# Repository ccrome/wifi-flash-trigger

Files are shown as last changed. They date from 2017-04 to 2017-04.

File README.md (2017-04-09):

# wifi-flash-trigger
ESP8266 + Arduino Wifi Flash trigger for high speed photography.  Uses esp-link as the wifi link to arduino

## Download esp-link
It’s here: https://github.com/jeelabs/esp-link/releases.

## Firmware versions:
esp-link: This seems to only work with esp-link v3.0.alpha0 - 2016-10-23, d0377bd.  https://github.com/jeelabs/esp-link
el-client: https://github.com/jeelabs/el-client (d559214ada405739fa235b13c7e2b42175ddbe95 tested)

## Flash the ESP8266
Flash to the esp8266: as per these instructions: https://github.com/jeelabs/esp-link/blob/master/FLASHING.md

esptool.py --port /dev/ttyUSB0 --baud 230400 write_flash -fs 32m -ff 80m 0x00000 boot_v1.6.bin 0x1000 user1.bin 0x3FC000 esp_init_data_default.bin 0x3FE000 blank.bin

## Warning
The esp-link in the webserver_controls.ino has debugging enabled

```ELClient esp(&Serial, &Serial);```

This totally breaks things. Be sure to have debugging disabled if you wish for things to work
```ELClient esp(&Serial);```

## Cofigure the esp-link
Connect to 192.168.4.1 and set the settings to this:

|RESET     | gpio12   |
|----------|----------|
|ISP/Flash | disabled |
|Conn LED  | disabled |
|Serial LED| GPIO14   |
|UART Pins | swapped  |

![flash-trigger_bb](https://cloud.githubusercontent.com/assets/286973/24841090/76d5db74-1d30-11e7-9619-d6fc9f7f678d.png)

## connect up the arduino:
5 wires:  BE SURE TO USE A 3.3V ARDUINO, or use a level shifter

|NAME    |NODEMCU PIN | ESP8266 pin | ARDUINO pin |      |
|--------|--------|---------|---------|------|
|        |GND     | G       |         | GND  |
|        |VCC     | 3V      |         | VCC  |
|        |RESET   | D6      | GPIO12  | RST  |
|        |ESPRX   | D7      | GPIO13  | TX   |
|        |ESPTX   | D8      | GPIO15  | RX   |

## Flash the arduino
Be sure that nothing else (like a web browser) is accessing 192.168.4.1, or avrdude will break.

```
$ avrdude -p m328p -c stk500v1 -e -U flash:w:.pioenvs/pro8MHzatmega328/firmware.hex -P net:192.168.4.1:23

avrdude: AVR device initialized and ready to accept instructions

Reading | ################################################## | 100% 0.01s

avrdude: Device signature = 0x1e950f (probably m328p)
avrdude: erasing chip
avrdude: reading input file ".pioenvs/pro8MHzatmega328/firmware.hex"
avrdude: input file .pioenvs/pro8MHzatmega328/firmware.hex auto detected as Intel Hex
avrdude: writing flash (1592 bytes):

Writing | ################################################## | 100% 0.48s

avrdude: 1592 bytes of flash written
avrdude: verifying flash memory against .pioenvs/pro8MHzatmega328/firmware.hex:
avrdude: load data flash data from input file .pioenvs/pro8MHzatmega328/firmware.hex:
avrdude: input file .pioenvs/pro8MHzatmega328/firmware.hex auto detected as Intel Hex
avrdude: input file .pioenvs/pro8MHzatmega328/firmware.hex contains 1592 bytes
avrdude: reading on-chip flash data:

Reading | ################################################## | 100% 0.93s

avrdude: verifying ...
avrdude: 1592 bytes of flash verified

avrdude: safemode: Fuses OK (E:00, H:00, L:00)

avrdude done.  Thank you.

```

Sometimes when it fails with
'not in sync'

```
ioctl("TIOCMGET"): Inappropriate ioctl for device
ioctl("TIOCMGET"): Inappropriate ioctl for device
avrdude: stk500_getsync() attempt 1 of 10: not in sync: resp=0x45
avrdude: stk500_getsync() attempt 2 of 10: not in sync: resp=0x4c
avrdude: stk500_getsync() attempt 3 of 10: not in sync: resp=0x2d
avrdude: stk500_getsync() attempt 4 of 10: not in sync: resp=0x43
avrdude: stk500_getsync() attempt 5 of 10: not in sync: resp=0x6c
avrdude: stk500_getsync() attempt 6 of 10: not in sync: resp=0x69
avrdude: stk500_getsync() attempt 7 of 10: not in sync: resp=0x65
avrdude: stk500_getsync() attempt 8 of 10: not in sync: resp=0x6e
avrdude: stk500_getsync() attempt 9 of 10: not in sync: resp=0x74
avrdude: stk500_getsync() attempt 10 of 10: not in sync: resp=0x20
```

this can help:

```../../esp-link-v3.0.14-g963ffbb/avrflash  192.168.4.1 .pioenvs/pro8MHzatmega328/firmware.hex ```

## Troubleshooting
* Before flashing the AVR, be sure to set the uC console speed in the web page to 57600
* After flashing the AVR, set console speed to 38400 (for 3.3v AVR)
* When flashing the AVR, be sure to close all web pages accessing the esp8266
* When using a 3.3V AVR, be sure that your serial port speed is set to 38400 or lower.
* After flashing the AVR power cycle the ESP8266.
* Then you should be able to see the uC RESET connect to the ESP in the console window.

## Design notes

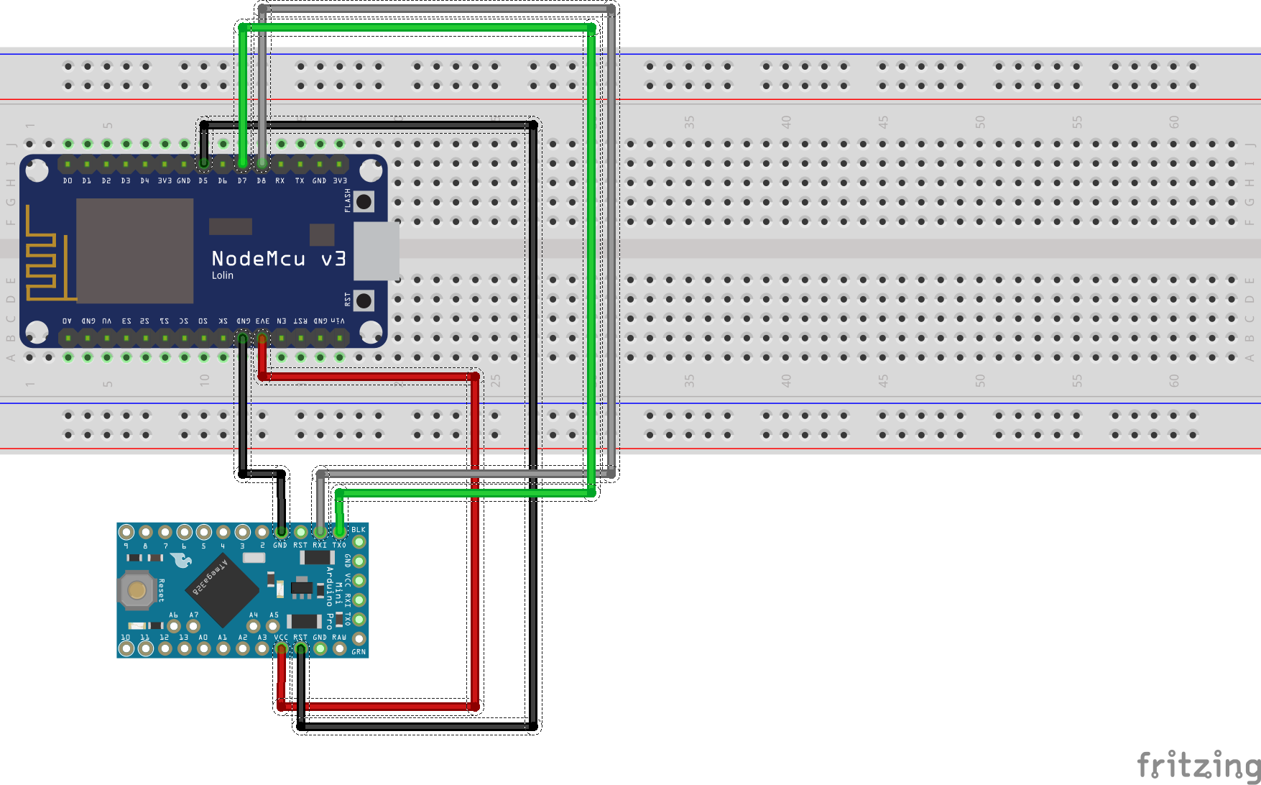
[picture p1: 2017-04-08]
trigger-schematic/flash-trigger_bb.png

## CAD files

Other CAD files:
simple-flash-trigger/inventor/arduino.ipt
simple-flash-trigger/inventor/box_bottom.ipt
simple-flash-trigger/inventor/flash assy.iam
simple-flash-trigger/inventor/headphone jack.ipt
simple-flash-trigger/inventor/potentiometer.ipt
simple-flash-trigger/inventor/switch.ipt

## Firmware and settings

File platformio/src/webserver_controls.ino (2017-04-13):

/**
 * This is a sample for trying out each HTML control
 * 
 * Test board:
 *    ESP8266 RX    <--level shifter-->    Arduino TX
 *    ESP8266 TX    <--level shifter-->    Arduino RX
 *    ESP8266 GPIO0 <--level shifter-->    Arduino RESET   (optional)
 *    
 *    Arduino LED is on PIN 13
 *    Connect an 1K trimmer to Arduino (voltage):  VCC <-> A0 <-> GND
 * 
 * 
 * Video:
 *    https://www.youtube.com/watch?v=vBESCO0UhYI
 */

#include <ELClient.h>
#include <ELClientWebServer.h>
#include "Pages.h"

// Initialize a connection to esp-link using the normal hardware serial port
//
// DEBUG is disasbled as
// - packet logging is slow and UART receive buffer can overrun (HTML form submission)
ELClient esp(&Serial);

// Initialize the Web-Server client
ELClientWebServer webServer(&esp);


// Callback made form esp-link to notify that it has just come out of a reset. This means we
// need to initialize it!
void resetCb(void) {
  Serial.println("EL-Client (re-)starting!");
  bool ok = false;
  do {
    ok = esp.Sync();      // sync up with esp-link, blocks for up to 2 seconds
    if (!ok) Serial.println("EL-Client sync failed!");
  } while(!ok);
  Serial.println("EL-Client synced!");
  
  webServer.setup();
}

void setup()
{
  Serial.begin(57600);
  
  esp.resetCb = resetCb;
  
  // ledInit();
  userInit();
  voltageInit();
  flashInit();
  resetCb();
}

void loop()
{
  esp.Process();
  flashLoop();
  // ledLoop();
  voltageLoop();
}

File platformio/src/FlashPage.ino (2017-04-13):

#include <ELClientWebServer.h>
// Use Timer 1 (16-bit) for input capture & output compare for high precision timing.
#define CLK_FREQUENCY (8000000.0)
// valid values are 1, 8, 64, 256, 1024
#define TIMER1_PRESCALE (256)
#define TIMER1_FREQUENCY (CLK_FREQUENCY/TIMER1_PRESCALE)

#define INPUT_CAPTURE_PIN 8
#define FLASH_OUTPUT_PIN 7
#define LED_PIN 13
//                                                                  +---------------------------------------------------------+
// Timer state machine:                                             V                                                         | yes
// IDLE ---->  WAITING_FOR_TRIGGER ----> INITIAL_DELAY -----> HOLD_TIME -> REPEAT_TIME_MINUS_HOLD ----> MORE FLASHES TO GO? ---
//                    ^                                                                                                       | no
//                    |------------- EXTRA_DELAY <----------------------------------------------------------------------------+
//
// start trigger whenever entering HOLD_TIME
// stop trigger whenever exiting HOLD_TIME

typedef enum
{
    IDLE = 0,
    WAITING_FOR_TRIGGER = 1,
    INITIAL_DELAY = 2, 
    HOLD_TIME = 3,
    REPEAT_TIME_MINUS_HOLD = 4,
    EXTRA_DELAY = 5,
} flash_sm_t;

typedef enum {
    UNKNOWN = 0,
    SOUND,
    LIGHT,
} flash_mode_t;

typedef struct {
    flash_mode_t mode;
    int extra_delay_ms; // minimum waiting time between triggers
    float initial_delay_ms;
    int repeat_count;
    float repeat_delay_ms;
    float hold_time_ms;
    flash_sm_t flash_sm;
    int repeats_to_go;
    int flash_output_pin;
    unsigned long triggered_at;
    int trigger_display_flag;
} flash_config_t;

flash_config_t flash_config;

void timer1_config(int e);
void flashRefreshCb(char * url);

void init_flash_config()
{
    memset(&flash_config, 0, sizeof(flash_config));
    flash_config.initial_delay_ms = 5.0;
    flash_config.repeat_delay_ms = 3.0;
    flash_config.repeat_count = 1;
    flash_config.hold_time_ms = .25; // on full power, speedlites can be up to 4ms...
    flash_config.extra_delay_ms = 200.0;
    flash_config.flash_output_pin = FLASH_OUTPUT_PIN ;
    flash_config.mode = SOUND;
}

void flashLoop()
{ 
    if (((millis() - flash_config.triggered_at) > 5000) &&
        flash_config.trigger_display_flag)
    {
        flash_config.trigger_display_flag = 0;
        flashRefreshCb(NULL);
    }
}

// called at button pressing
void flashButtonPressCb(char * button)
{ 
    String btn = button;
    if( btn == F("btn_light") )
        flash_config.mode = LIGHT;
    else if( btn == F("btn_sound") )
        flash_config.mode = SOUND;
}

// setting the value of a field
//
// handle data as fast as possible
// - huge HTML forms can arrive in multiple packets
// - if this method is slow, UART receive buffer may overrun
void flashSetFieldCb(char * field)
{
    String fld = field;
    if( fld == F("initial_delay_ms") )
        flash_config.initial_delay_ms = webServer.getArgFloat();
    else if( fld == F("repeat_count") )
        flash_config.repeat_count = webServer.getArgInt();
    else if( fld == F("repeat_delay_ms") )
        flash_config.repeat_delay_ms = webServer.getArgFloat();
    else if (fld == F("flash_mode") ) {
        String mode = webServer.getArgString();
        flash_config.mode = mode == F("light") ? LIGHT : SOUND;
    }
        
        
}

// called at page refreshing
void flashRefreshCb(char * url)
{
    String s;
    switch (flash_config.mode)
    {
    case SOUND: s += "Sound Trigger Mode<br>"     ; break;
    case LIGHT: s += "Light Trigger Mode<br>"     ; break;
    default   : s += "Unknown Trigger Mode<br>"   ; break;
    }
    if (flash_config.trigger_display_flag)
        s += "<H1>Triggered!</H1>";
    s+= "Initial Delay: " + String(flash_config.initial_delay_ms) + "ms<br>";
    s+= "Repeat Count: " + String(flash_config.repeat_count) + "<br>";
    s+= "Repeat Delay: " + String(flash_config.repeat_delay_ms) + "ms<br>";
    webServer.setArgString(F("text"), s.c_str());
}

// called at page loading
void flashLoadCb(char * url)
{
    webServer.setArgFloat(F("initial_delay_ms"), flash_config.initial_delay_ms);
    webServer.setArgInt(F("repeat_delay_ms"),  flash_config.repeat_delay_ms);
    webServer.setArgFloat(F("repeat_count"),     flash_config.repeat_count);
    webServer.setArgString(F("flash_mode"), flash_config.mode == SOUND ? F("sound") : F("light"));
    flashRefreshCb( url );
}

void enable_output_compare()
{
    TIFR1 = 0xff; // clear pending interrupts
    // TIMSK1 |= (1<<1);
    TIMSK1 = (1<<1);
}
void disable_output_compare()
{
    // TIMSK1 &= ~(1<<1); // disable output compare
    TIMSK1 = 0;
    TIFR1 = 0xff;         // and it's flag
}

void enable_input_capture()
{
    TIFR1 = 0xff; // clear pending interrupts
    // TIMSK1 |= (1<<5); // enable input capture
    TIMSK1 = (1<<5); // enable input capture
}

void disable_input_capture()
{
    // TIMSK1 &= ~(1<<5); // disable input capture
    TIMSK1 = 0;
    TIFR1 = 0xff; // clear input capture flag
    
}

void flash_sm_init()
{
    flash_trigger_off();
    flash_config.repeats_to_go = flash_config.repeat_count;
    flash_config.flash_sm = WAITING_FOR_TRIGGER;
    timer1_config(1);
    disable_output_compare();
    enable_input_capture();
}

// FLASH setup code
void flashInit()
{
    init_flash_config();
    pinMode(FLASH_OUTPUT_PIN, OUTPUT);
    pinMode(INPUT_CAPTURE_PIN, INPUT);
    pinMode(LED_PIN,          OUTPUT);
    URLHandler *flashHandler = webServer.createURLHandler(F("/FlashConfig.html.json"));
    flashHandler->buttonCb.attach(flashButtonPressCb);
    flashHandler->setFieldCb.attach(flashSetFieldCb);
    flashHandler->loadCb.attach(flashLoadCb);
    flashHandler->refreshCb.attach(flashRefreshCb);
    flash_sm_init();
}

void report_error(int error_code)
{
    while(1) {
        for (int i = 0; i < error_code; i++) {
            digitalWrite(LED_PIN, !digitalRead(LED_PIN));
            delay(250);
            digitalWrite(LED_PIN, !digitalRead(LED_PIN));
            delay(250);
        }
        delay(3000);
    }
}

void flash_trigger_off()
{
    digitalWrite(flash_config.flash_output_pin, 0);
}

void flash_trigger_on()
{
    digitalWrite(flash_config.flash_output_pin, 1);
}

unsigned int ms_2_counts(float milliseconds)
{
    return round(milliseconds / 1000.0 * TIMER1_FREQUENCY);   // ms * s/ms * counts/second  = counts
}
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
